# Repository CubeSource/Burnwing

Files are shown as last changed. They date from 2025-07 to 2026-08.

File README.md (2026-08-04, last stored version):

# Burnwing

Burnwing is a burnwire development PCB.

## Features

* Dual-purpose engineering model/flight model to assist in the development of thermal knife release mechanisms and testing of deployables.
    * Optionally, snap off the dev kit portion.
* Powered by USB C with selectable current and voltage limits for easy testing or by picoblade/picolock connectors.
* Default 5V, 1A 

## Renders

### Top

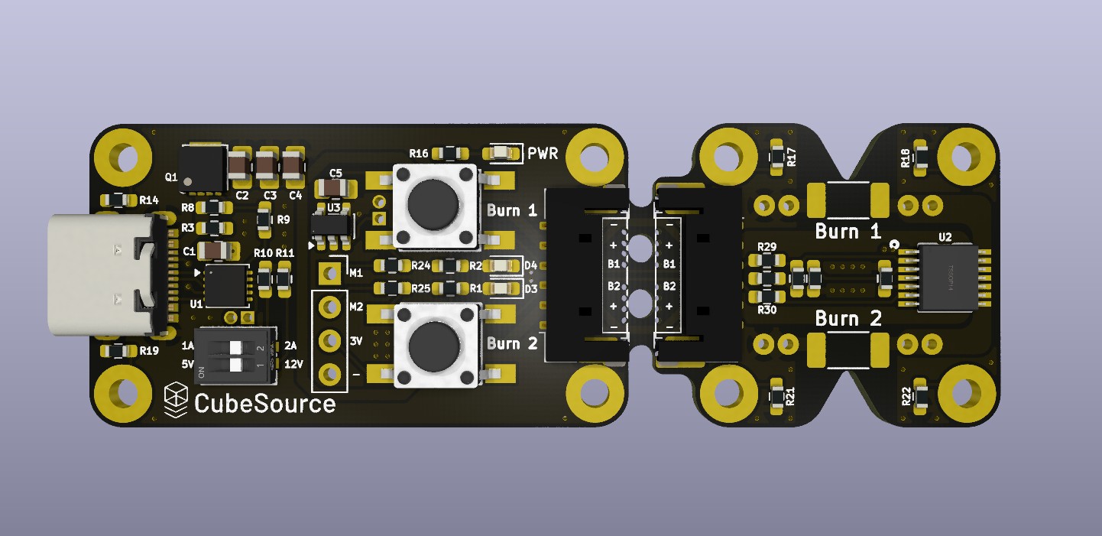
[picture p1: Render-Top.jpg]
Burnwing Rev 3.0 — top


### Bottom

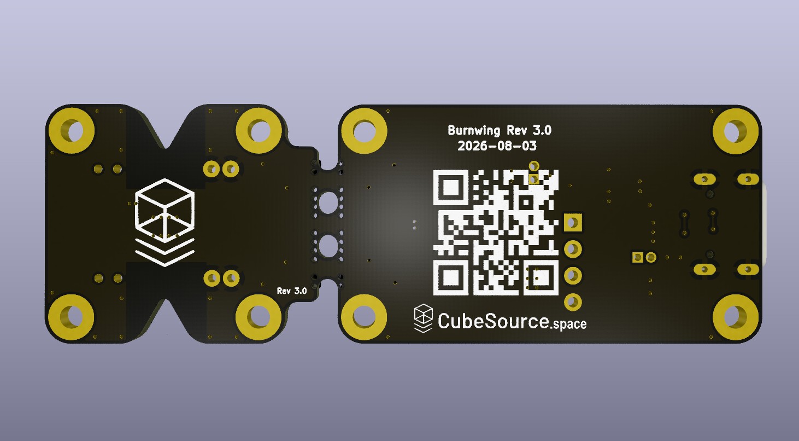
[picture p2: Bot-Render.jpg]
Burnwing Rev 3.0 — bottom


## Additional Resources

* https://www.cubesource.space/resources
* https://docs.google.com/spreadsheets/d/1-gqduE5_rplaJSyHokB8z7FWwOto8bMK/edit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

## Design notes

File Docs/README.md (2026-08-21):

# Burnwing
A dual-purpose engineering/flight model designed to assist in the development of thermal knife release mechanisms and testing of satellite deployables.

## Features
* The dev kit (engineering model) portion includes mouse bites, allowing it to be fully separated from the flight model.
* USB C PD Powered with selectable current and voltage limits for easy testing, or powered through the PicoBlade / Pico-Lock connectors.
* Supply range 5.0-15.0 V, 12 V flight baseline, 18.0 V absolute maximum. The DIP voltage legends (5 V / 12 V) are exact; the current legends read 1 A / 2 A while the values actually requested over USB-PD are 1.25 A / 2.25 A.
* Integrated ESD, Over Temperature, Over Current and Reverse Polarity Protection.

## Renders

### Isometric

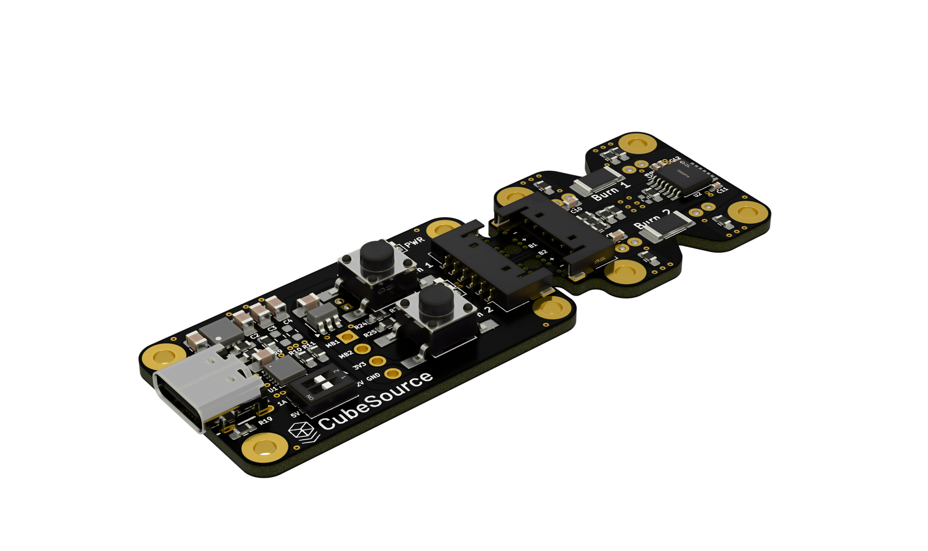
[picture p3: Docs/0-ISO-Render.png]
Burnwing Rev 3.0 — isometric


### Top

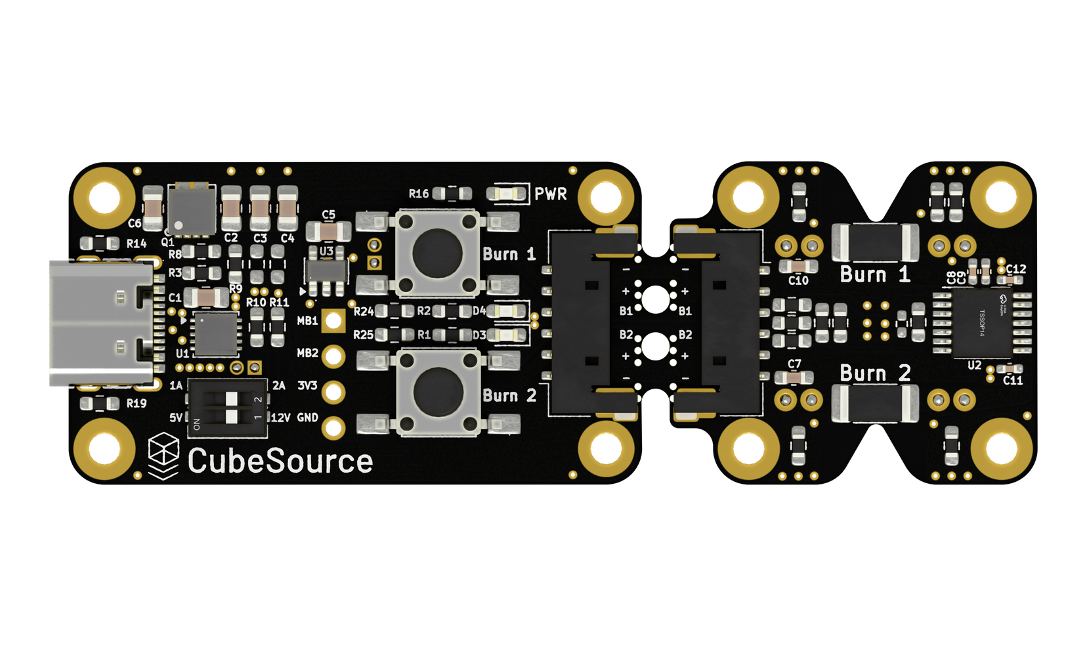
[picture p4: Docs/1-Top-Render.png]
Burnwing Rev 3.0 — top


### Bottom

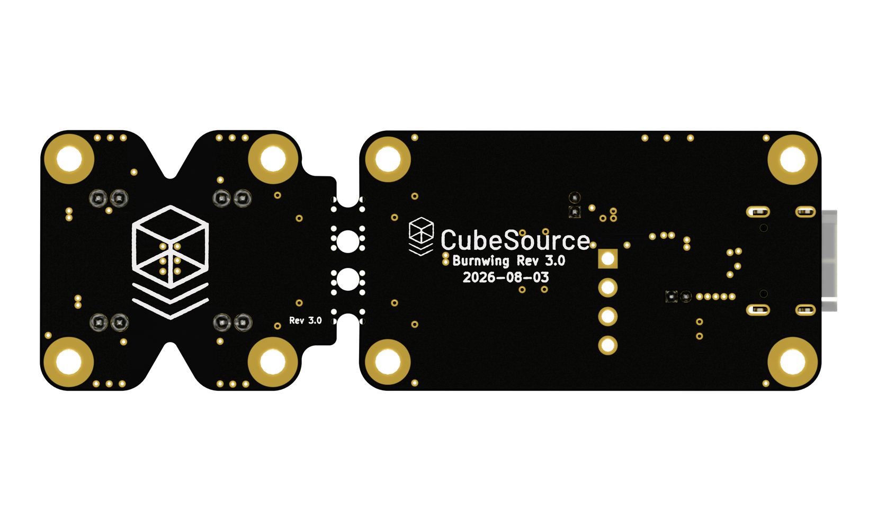
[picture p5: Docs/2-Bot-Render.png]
Burnwing Rev 3.0 — bottom


## Additional Resources

* https://www.cubesource.space/resources
* https://docs.google.com/spreadsheets/d/1-gqduE5_rplaJSyHokB8z7FWwOto8bMK/edit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

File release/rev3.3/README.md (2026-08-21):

# Burnwing Rev 3.0 Production Files

Fabrication and assembly output for the Burnwing Rev 3.0 board, generated from commit `caff272` and carried by the `rev3.3` tag (`df94088`).

Burnwing is a dual-channel thermal knife release mechanism designed for CubeSats and small satellites. It ships as a unified panel carrying two sections joined by mouse bites: a **Flight Model (FM)** and a break-away **Engineering Model (EM)** test fixture.

---

## Features

- **Dual-Purpose Panel**: The break-away Engineering Model (EM) test fixture allows full benchtop testing and can be separated via mouse bites prior to flight integration.
- **USB-C PD Powered**: Selectable voltage and current limits for straightforward lab testing, or powered via Molex PicoBlade / Pico-Lock connectors.
- **Comprehensive Protection**: Integrated ESD protection, over-temperature protection, over-current limiting, and reverse polarity protection.

## Notable Improvements (Rev 2 → Rev 3)

- **Reversible 6-Pin Cable Pinout**: Enables the use of unmodified COTS Molex wire harnesses without polarity orientation errors.
- **High-Side Control Architecture**: Switched from low-side switching (NCV8402ADDR2G) to an Infineon BTS7030-2EPA high-side smart power switch. This keeps the burn elements unenergized until triggered and supports both 3.3V and 5V logic inputs.

---

## Production Files & Release Assets

| File | Description |
|---|---|
| `GERBER-Burnwing-rev3.3.zip` | 9 Gerber layers, PTH/NPTH Excellon drill files with maps, and the `.gbrjob` |
| `BOM-Burnwing-rev3.3.csv` | SMT Bill of Materials (29 line items, 48 placements, every line carrying an LCSC code) |
| `CPL-Burnwing-rev3.3.csv` | Component Placement List (48 placements, including hybrid through-hole parts) |
| `Burnwing-Schematic-rev3.3.pdf` | Complete circuit schematic |
| `Burnwing-rev3.3.step` | 3D CAD assembly model (DNP components excluded) |

---

## Board Specifications

- **Layers**: 2 layers, 1.6 mm thickness
- **Finish**: ENIG (Electroless Nickel Immersion Gold), black solder mask
- **Supply Voltage**: 5.0 V to 15.0 V nominal (12.0 V flight baseline, 18.0 V absolute maximum)
- **Vias**: All 71 vias are untented for thermal and probing accessibility

### DIP switch settings

The voltage legends (5 V / 12 V) are exact. The current legends read 1 A and 2 A; the values actually requested over USB-PD are **1.25 A and 2.25 A**, because the current-select resistor decodes to the nearest tabulated step. This is a ceiling negotiated with the supply rather than a current the board draws, and the board's own requirement is 1.0 A per channel, so neither setting under-supplies it.

---

## Read Before Ordering Assembly

**The CPL includes through-hole footprints deliberately.** `J2`, the USB-C receptacle, is a hybrid part declared `through_hole`. An SMD-only position export drops it and lists 47 parts instead of the correct 48. Do not re-export the position file as SMD-only.

**Two parts must be consigned or hand-fitted, and must come off the uploaded assembly BOM.** Neither is orderable through the assembly house:

| Ref | Part | Reason |
|---|---|---|
| U1 | HUSB238_002DD (C7471904) | Zero supplier stock in the DFN-10 package. Stock held by CubeSource |
| R12, R13 | RR01J36RTB | Burn elements, not an LCSC part. Marked do-not-populate; fitted by CubeSource |

**U2 stock is thin.** The BTS7030-2EPA (C534836) is the flight high-side driver, has no second source in the design, and stood at 433 units. Worth confirming before committing to a run.

---

## Verification & Status

- **ERC**: 0 violations.
- **DRC**: 0 violations beyond the Q1 library note below, 0 unconnected pads, 0 schematic-parity issues.
- **BOM & CPL Parity**: Schematic, board, and the JLCPCB plugin database agree on every part number, so a BOM taken from any of the three orders the same parts. 48-placement CPL.

Eight checks carry reduced severity in the project's rule set and are therefore not represented in those totals: hole-to-copper clearance, solder-mask bridging, courtyard overlap, missing courtyard, silkscreen over copper, silkscreen to board edge, non-plated hole inside courtyard, and footprint filter match.

### Known items

- The Q1 footprint on the board declares the SMD footprint type while the `POWERDI3333` library copy does not, so DRC reports one `lib_footprint_mismatch`. The board is the correct side and Q1 appears in the position file; the warning clears when `(attr smd)` is added to the library footprint. Fixed on `main` in `85b867c` (2026-08-21); the published rev3.3 files predate that commit and still carry the warning.
- `R14` and `R19` are 0 Ω jumpers on the engineering half. The schematic and board specify `C100044`; the JLCPCB plugin database holds `C141796` for the same two parts. Both are 0 Ω 0603, and the flight-half jumpers are unaffected.
- `R33` is a do-not-populate 0 Ω position whose land pattern is 0402 while the assigned part is an 0603 device. Not fitted, so no build is affected.

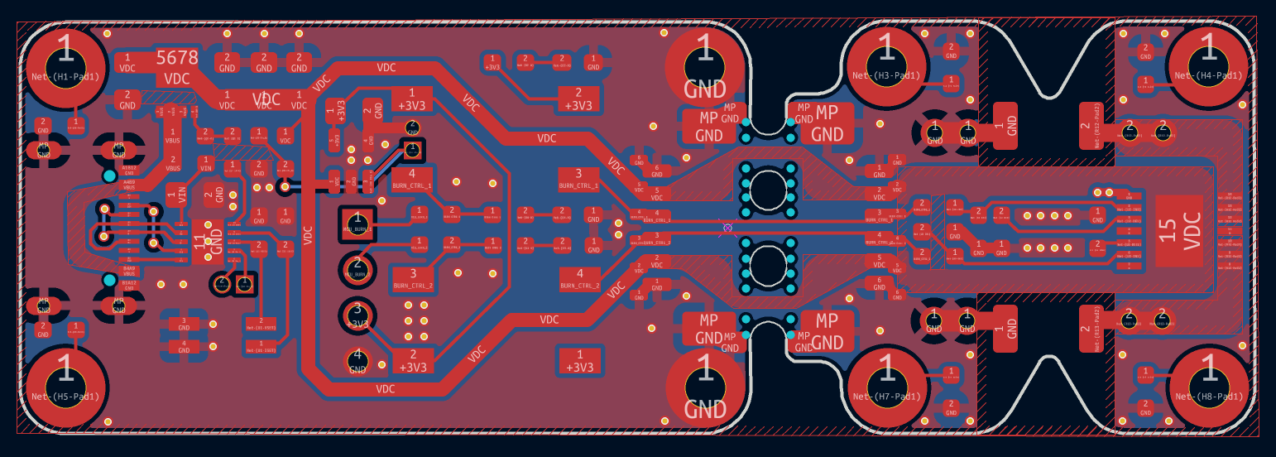
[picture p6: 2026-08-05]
Docs/3-Top-Copper-Layers.png

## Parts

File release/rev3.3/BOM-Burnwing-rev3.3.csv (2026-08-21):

Designator | Comment | Footprint | LCSC | Quantity
Burn1,Burn2 | TSA063G43-250 | Burnwing:KEY-SMD_4P-L6.0-W6.0-P4.50-LS10.0 | C294564 | 2
C1,C4 | 1uF/50V | Burnwing:C_0805_2012Metric_Pad1.18x1.45mm_HandSolder | C28323 | 2
C2,C3,C5,C6 | 4.7uF | Burnwing:C_0805_2012Metric_Pad1.18x1.45mm_HandSolder | C437557 | 4
C7,C10 | 10uF | Capacitor_SMD:C_0603_1608Metric_Pad1.08x0.95mm_HandSolder | C697423 | 2
C8 | 47nF | Capacitor_SMD:C_0402_1005Metric_Pad0.74x0.62mm_HandSolder | C368599 | 1
C9,C11,C12 | 100nF | Capacitor_SMD:C_0402_1005Metric_Pad0.74x0.62mm_HandSolder | C85858 | 3
D3,D4 | LED | Burnwing:LED_0603_1608Metric_Pad1.05x0.95mm_HandSolder | C2286 | 2
D7 | PWR | Burnwing:LED_0603_1608Metric_Pad1.05x0.95mm_HandSolder | C2286 | 1
J2 | USB Type C | Burnwing:USB-C-SMD_G-SWITCH_GT-USB-7010ASV | C2988369 | 1
J5 | Conn_01x06_MountingPin | Burnwing:Molex_Pico-Lock_and_PicoBlade_Mirror | C563981 | 1
J6 | Conn_01x06_MountingPin | Burnwing:Molex_Pico-Lock_and_PicoBlade | C563981 | 1
Q1 | AONR21307 | Burnwing:POWERDI3333 | C3277813 | 1
R1,R2,R16 | 1k5 | Burnwing:R_0603_1608Metric_Pad0.98x0.95mm_HandSolder | C22843 | 3
R3 | 10 | Burnwing:R_0603_1608Metric_Pad0.98x0.95mm_HandSolder | C203240 | 1
R8 | 49k9 | Burnwing:R_0603_1608Metric_Pad0.98x0.95mm_HandSolder | C705780 | 1
R9 | 5k1 | Burnwing:R_0603_1608Metric_Pad0.98x0.95mm_HandSolder | C105580 | 1
R10 | 10K | Burnwing:R_0603_1608Metric_Pad0.98x0.95mm_HandSolder | C116677 | 1
R11 | 14K | Burnwing:R_0603_1608Metric_Pad0.98x0.95mm_HandSolder | C881028 | 1
R14,R19 | 0 | Burnwing:R_0603_1608Metric_Pad0.98x0.95mm_HandSolder | C100044 | 2
R17,R18,R21,R22 | 0 | Burnwing:R_0603_1608Metric_Pad0.98x0.95mm_HandSolder | C141796 | 4
R23,R26 | 10k | Burnwing:R_0603_1608Metric_Pad0.98x0.95mm_HandSolder | C116677 | 2
R24,R25 | 330 | Burnwing:R_0603_1608Metric_Pad0.98x0.95mm_HandSolder | C23138 | 2
R27,R28 | 22k | Burnwing:R_0603_1608Metric_Pad0.98x0.95mm_HandSolder | C144680 | 2
R29,R30 | 3k | Burnwing:R_0603_1608Metric_Pad0.98x0.95mm_HandSolder | C445829 | 2
R32 | 47 | Burnwing:R_0603_1608Metric_Pad0.98x0.95mm_HandSolder | C144656 | 1
SW1 | SW_DIP_x02 | Burnwing:2_Dipswitch | C7430304 | 1
U1 | HUSB238 | Burnwing:WDFN-10-1EP_3x3mm_P0.5mm_EP1.8x2.5mm | C7471904 | 1
U2 | BTS7030-2EPA | Burnwing:PG-TSDSO-14_L4.9-W3.9-P0.65-LS6.0-BL-EP | C534836 | 1
U3 | TPS70933QDBVRQ1 | Burnwing:SOT-23-5 | C90991 | 1

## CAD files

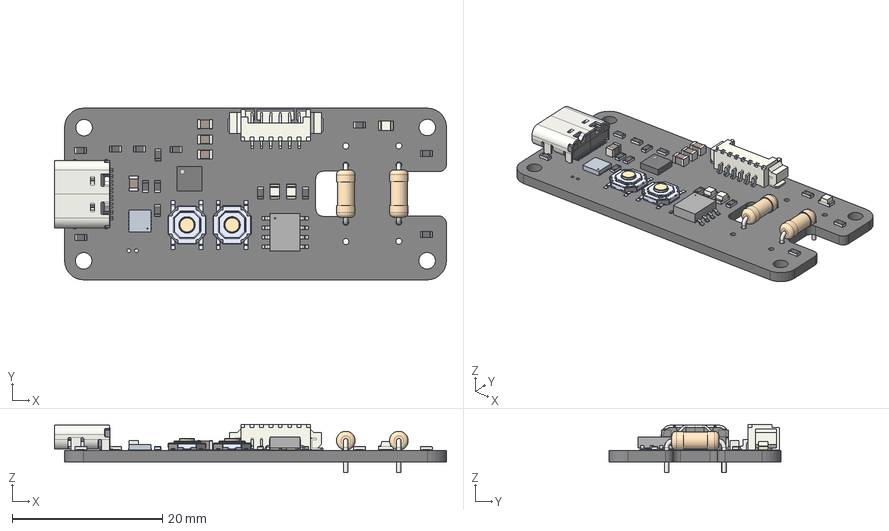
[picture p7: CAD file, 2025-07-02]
Burnwing.step
52.2 x 22.9 x 6.40 mm
C_0805_2012Metric x 4
R_0603_1608Metric x 14
R_Axial_DIN0207_L6.3mm_D2.5mm_P7.62mm_Horizontal x 2
USB_C_Receptacle_GCT_USB4105-xx-A_16P_TopMnt_Horizontal
LED_0805_2012Metric x 3
Molex_PicoBlade_53261-0671_1x06-1MP_P1.25mm_Horizontal
TS-1187A-B-A-B--3DModel-STEP-56544 x 2
SO-8_STM
VSON-8_3.3x3.3mm_P0.65mm_NexFET
CTS-SAT-1-Burnwire-PCB_a4d4ea03 1.29.1
Burnwing_PCB

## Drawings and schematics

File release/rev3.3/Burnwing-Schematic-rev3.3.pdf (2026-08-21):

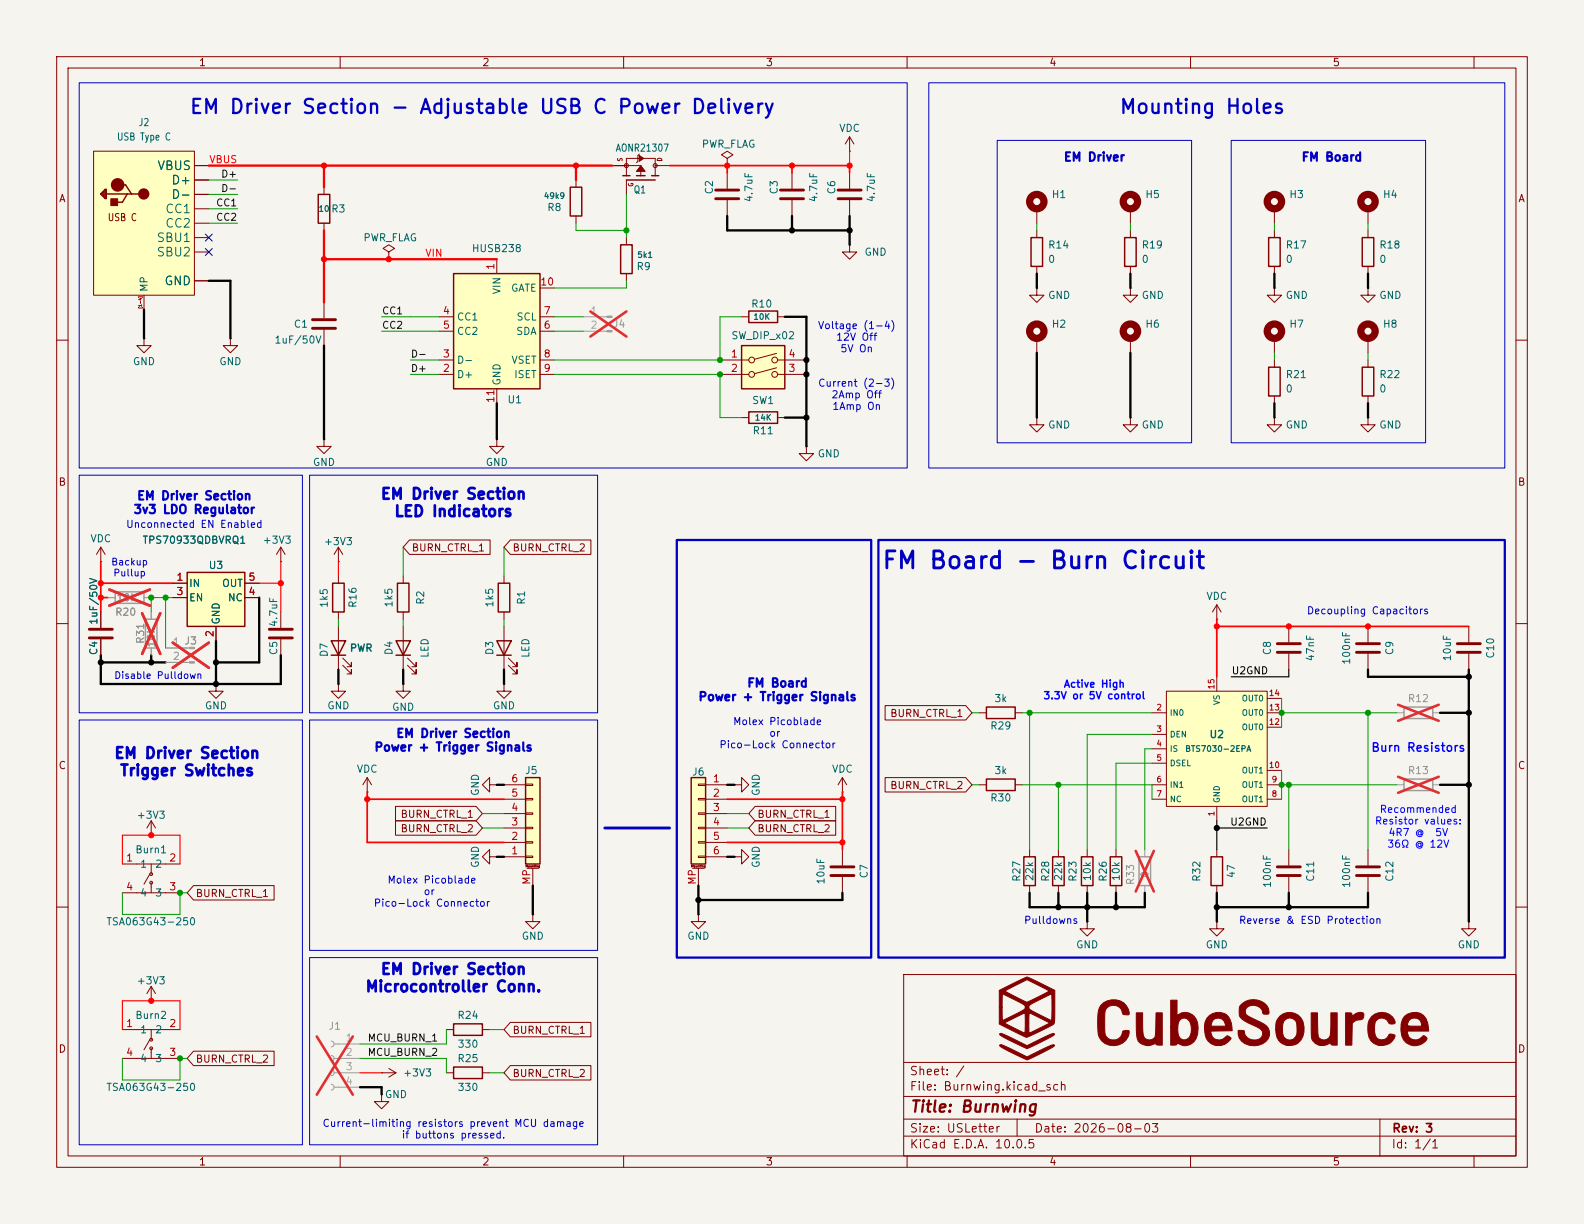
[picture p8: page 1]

Power + Trigger Signals Molex Picoblade or Pico-Lock Connector EM Driver Section - Adjustable USB C Power Delivery

Voltage (1-4) 12V Off 5V On Current (2-3)

2Amp Off 1Amp On Disable Pulldown Unconnected EN Enabled EM Driver Section

FM Board - Burn Circuit

Active High 3.3V or 5V control U3

Current-limiting resistors prevent MCU damage

Size: USLetter | Rev: 3
KiCad E.D.A. 10.0.5 | Id: 1/1

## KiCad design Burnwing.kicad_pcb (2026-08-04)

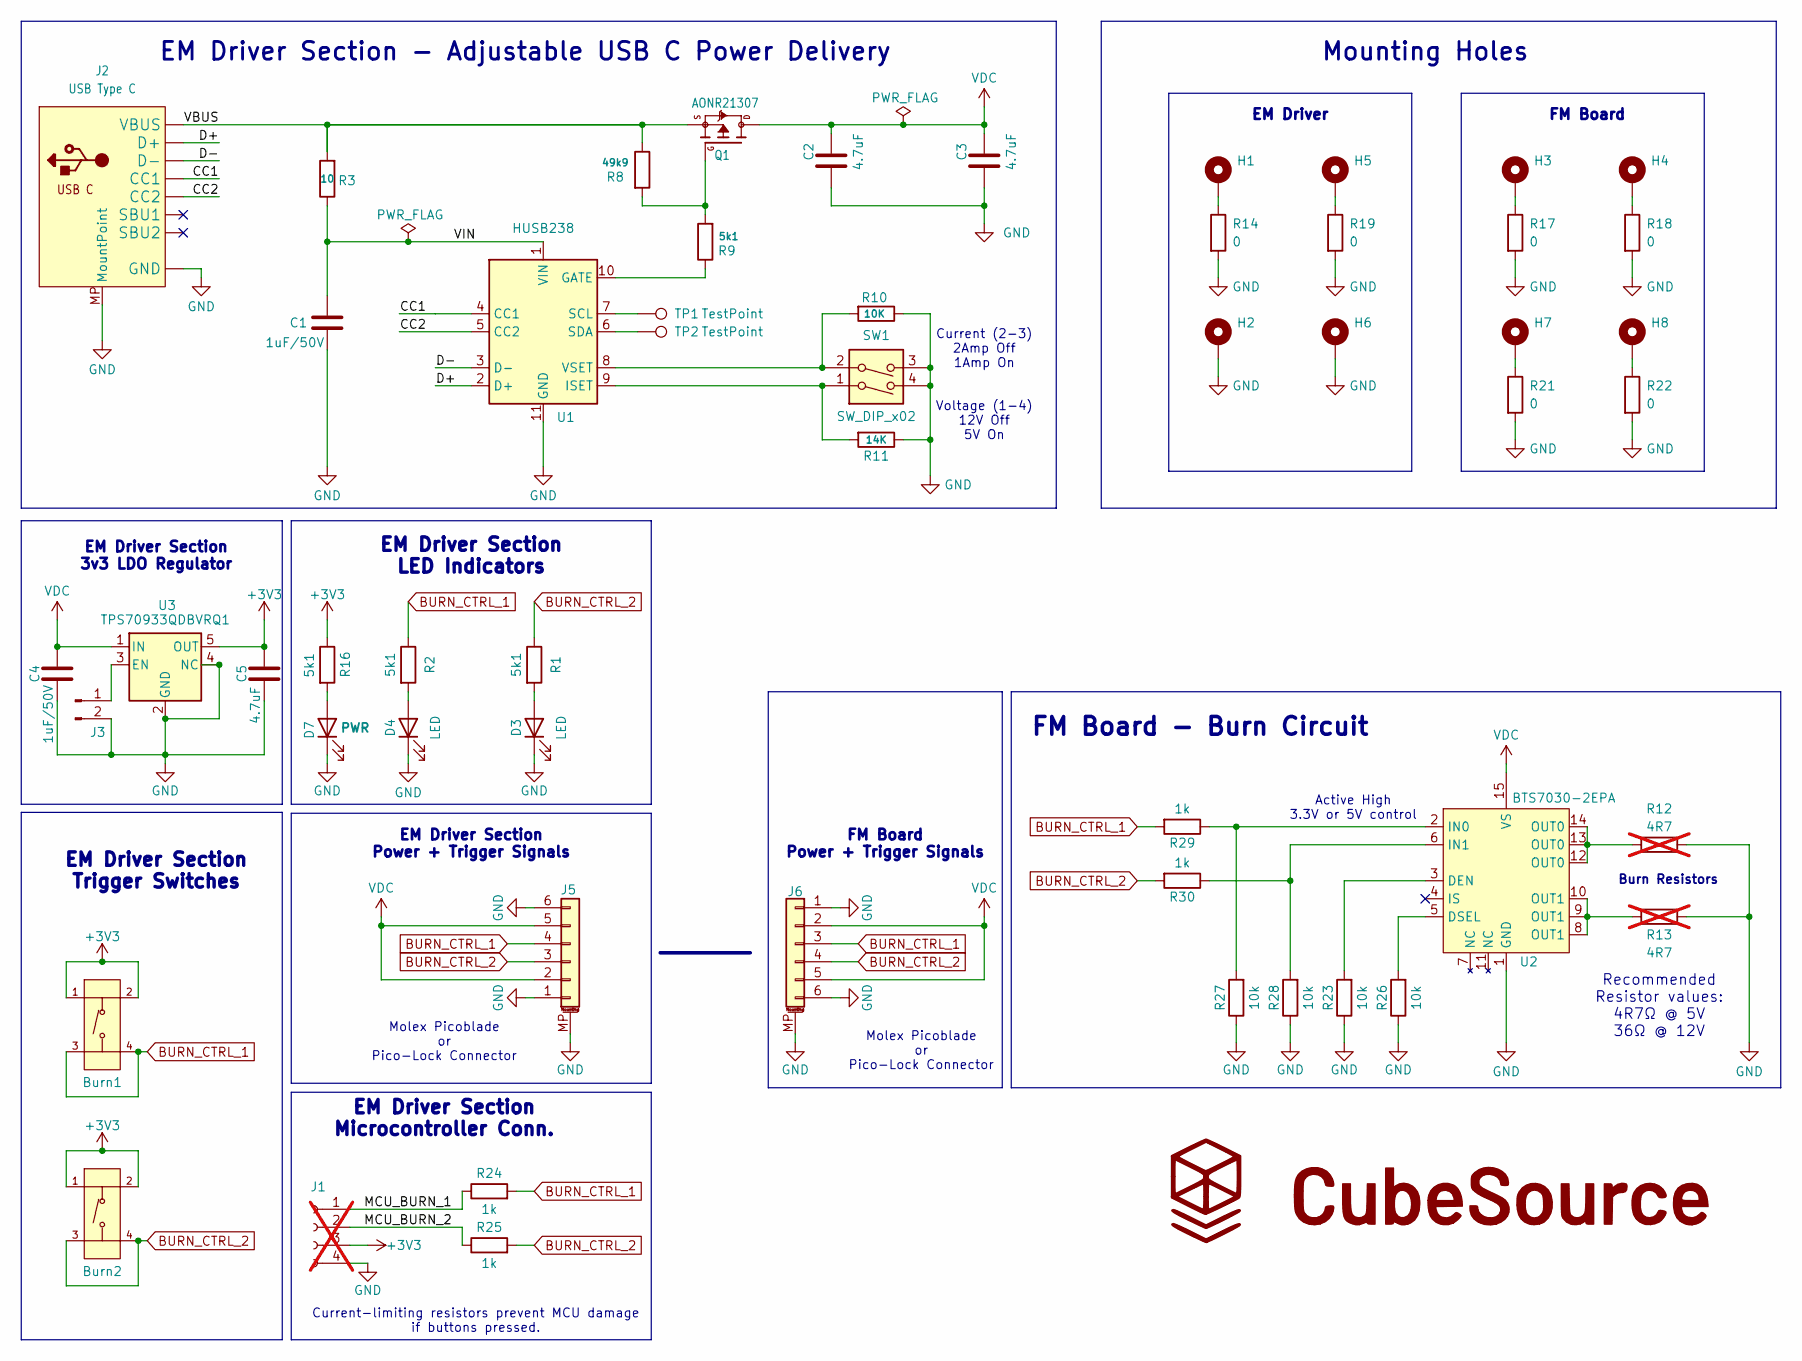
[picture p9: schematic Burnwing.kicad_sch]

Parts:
Burn1, Burn2: KEY-SMD_4P-L6.0-W6.0-P4.50-LS9.5-BR; Voltage Rating (Dc) 12V; Part TS-1187A-B-A-B; LCSC C318884
C1, C4: 1uF/50V; C_0805_2012Metric_Pad1.18x1.45mm_HandSolder; LCSC C28323
C2, C3, C5: 4.7uF; C_0805_2012Metric_Pad1.18x1.45mm_HandSolder; LCSC C437557
D3, D4: LED; LED_0603_1608Metric_Pad1.05x0.95mm_HandSolder; LCSC C94868
D7: PWR; LED_0603_1608Metric_Pad1.05x0.95mm_HandSolder; LCSC C94868
H1, H2, H3, H4, H5, H6, H7, H8: MountingHole_Pad; MountingHole_2.2mm_M2_Pad
J1: Conn_01x04_Socket; PinSocket_1x04_P2.54mm_Vertical; not fitted
J2: USB Type C; USB_C_CUSB31-CFM2AX-01-X; LCSC C2988369
J3: Conn_01x02_Pin; PinSocket_1x02_P1.27mm_Vertical
J5: Conn_01x06_MountingPin-Mirror; Molex_Pico-Lock_and_PicoBlade
J6: Conn_01x06_MountingPin; Molex_Pico-Lock_and_PicoBlade
Q1: AONR21307; POWERDI3333; LCSC C3277813
R1, R2, R9, R16: 5k1; R_0603_1608Metric_Pad0.98x0.95mm_HandSolder; LCSC C105580
R3: 10; R_0603_1608Metric_Pad0.98x0.95mm_HandSolder; LCSC C203240
R8: 49k9; R_0603_1608Metric_Pad0.98x0.95mm_HandSolder; LCSC C705780
R10: 10K; R_0603_1608Metric_Pad0.98x0.95mm_HandSolder; LCSC C95204
R11: 14K; R_0603_1608Metric_Pad0.98x0.95mm_HandSolder; LCSC C105580
R12, R13: 4R7; AxialBurnResistor_No_Cutout; not fitted
R14: 0; R_0603_1608Metric_Pad0.98x0.95mm_HandSolder; LCSC C100044
R17, R18, R19, R21, R22: 0; R_0603_1608Metric_Pad0.98x0.95mm_HandSolder
R23, R26, R27, R28: 10k; R_0603_1608Metric_Pad0.98x0.95mm_HandSolder
R24, R25, R29, R30: 1k; R_0603_1608Metric_Pad0.98x0.95mm_HandSolder
SW1: SW_DIP_x02; 2_Dipswitch
TP1, TP2: TestPoint
U1: HUSB238; WDFN-10-1EP_3x3mm_P0.5mm_EP1.8x2.5mm; LCSC C7471904
U2: BTS7030-2EPA; PG-TSDSO-14_L4.9-W3.9-P0.65-LS6.0-BL-EP; LCSC Part C534836
U3: TPS70933QDBVRQ1; SOT-23-5; LCSC C90991

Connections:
+3V3: Burn1.1 (A), Burn1.2 (B), Burn2.1 (A), Burn2.2 (B), C5.1, J1.3, R16.1, U3.5 (OUT)
/CC1: J2.A5 (CC1), U1.4 (CC1)
/CC2: J2.B5 (CC2), U1.5 (CC2)
/D+: J2.A6 (D+), J2.B6 (D+), U1.2 (D+)
/D-: J2.A7 (D-), J2.B7 (D-), U1.3 (D-)
/MCU_BURN_1: J1.1, R24.1
/MCU_BURN_2: J1.2, R25.1
/VBUS: J2.A4B9 (VBUS), J2.B4A9 (VBUS), Q1.1 (S), Q1.2 (S), Q1.3 (S), R3.2, R8.1
/VIN: C1.1, R3.1, U1.1 (VIN)
BURN_CTRL_1: Burn1.3 (C), Burn1.4 (D), J5.4, J6.3, R2.1, R24.2, R29.2
BURN_CTRL_2: Burn2.3 (C), Burn2.4 (D), J5.3, J6.4, R1.1, R25.2, R30.2
GND: C1.2, C2.2, C3.2, C4.2, C5.2, D3.1 (K), D4.1 (K), D7.1 (K), H2.1 (1_1), H6.1 (1_1), J1.4, J2.A1B12 (GND), J2.B1A12 (GND), J2.MP (MountPoint), J3.2, J5.1, J5.6, J5.MP (MountPin), J6.1, J6.6, J6.MP (MountPin), R10.1, R11.1, R12.1, R13.1, R14.2, R17.2, R18.2, R19.2, R21.2, R22.2, R23.1, R26.1, R27.1, R28.1, SW1.3, SW1.4, U1.11 (GND), U2.1 (GND), U3.2 (GND), U3.4 (NC); also elsewhere on the board
unnamed: D3.2 (A), R1.2
unnamed: D4.2 (A), R2.2
unnamed: D7.2 (A), R16.2
unnamed: H1.1 (1_1), R14.1
unnamed: H3.1 (1_1), R17.1
unnamed: H4.1 (1_1), R18.1
unnamed: H5.1 (1_1), R19.1
unnamed: H7.1 (1_1), R21.1
unnamed: H8.1 (1_1), R22.1
unnamed: J3.1, U3.3 (EN)
unnamed: Q1.4 (G), R8.2, R9.2
unnamed 23: R12.2, U2.12 (OUT0), U2.13 (OUT0), U2.14 (OUT0); also elsewhere on the board
unnamed 24: R13.2, U2.8 (OUT1), U2.9 (OUT1), U2.10 (OUT1); also elsewhere on the board
unnamed: R9.1, U1.10 (GATE)
unnamed: R11.2, SW1.1, U1.9 (ISET)
unnamed 27: TP1.1, U1.7 (SCL); also elsewhere on the board
unnamed 28: TP2.1, U1.6 (SDA); also elsewhere on the board
unnamed: R10.2, SW1.2, U1.8 (VSET)
unnamed: R23.2, U2.3 (DEN)
unnamed: R26.2, U2.5 (DSEL)
unnamed: R27.2, R29.1, U2.2 (IN0)
unnamed: R28.2, R30.1, U2.6 (IN1)
VDC: C2.1, C3.1, C4.1, J5.2, J5.5, J6.2, J6.5, Q1.5678 (D), U2.15 (VS), U3.1 (IN)

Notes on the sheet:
FM Board Power + Trigger Signals
FM Board
Mounting Holes
EM Driver Section 3v3 LDO Regulator
EM Driver Section LED Indicators
EM Driver Section - Adjustable USB C Power Delivery
FM Board - Burn Circuit
Molex Picoblade or Pico-Lock Connector
Recommended Resistor values: 4R7Ω @ 5V 36Ω @ 12V
EM Driver Section Power + Trigger Signals
EM Driver Section Trigger Switches
Voltage (1-4) 12V Off 5V On
Burn Resistors
Current (2-3) 2Amp Off 1Amp On
Current-limiting resistors prevent MCU damage if buttons pressed.
Active High 3.3V or 5V control
EM Driver Section Microcontroller Conn.
EM Driver

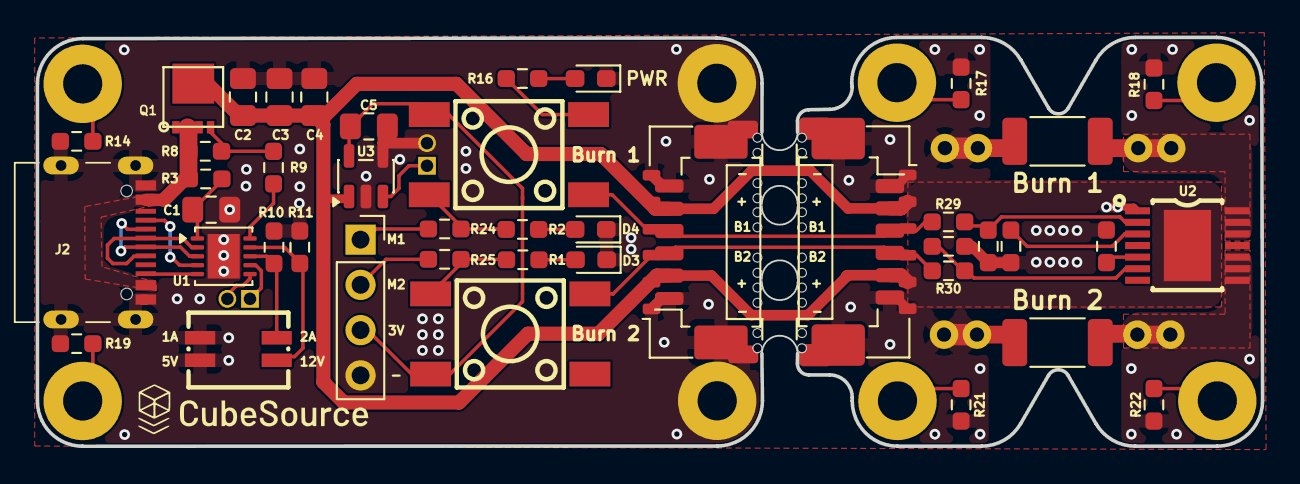
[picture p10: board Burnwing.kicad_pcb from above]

Board: 2 copper layers, 68.7 x 22.9 mm, 57 parts (1 on the bottom side), 35 nets.

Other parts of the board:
.space, .space#2: LOGO; CubeSource
Burn 1, Burn 2: R_2010_5025Metric_Pad1.40x2.65mm_HandSolder
J3#2: Conn_01x02_Pin; PinSocket_1x02_P1.27mm_Vertical

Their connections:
GND: Burn 1.1, Burn 2.1; also elsewhere on the board
unnamed 23: Burn 1.2; also elsewhere on the board
unnamed 24: Burn 2.2; also elsewhere on the board
unnamed 27: J3#2.1; also elsewhere on the board
unnamed 28: J3#2.2; also elsewhere on the board

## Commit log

2025-05-18 Initial upload
    Reupload of Rev1 to begin Rev2 updates
    [Burnwing.kicad_pcb, Burnwing.kicad_sch]
2025-06-22 Changed to USB C power
    Switched our regulator for selectable usb C power delivery
    [Burnwing.kicad_pcb, Burnwing.kicad_sch]
2025-06-22 Updated Schematic
    [Burnwing.kicad_sch]
2025-06-23 updated layou/schematic
    [Burnwing.kicad_pcb, Burnwing.kicad_sch]
2025-06-23 Routing updates
    [Burnwing.kicad_pcb, Burnwing.kicad_sch]
2025-06-26 Minor updates
    [Burnwing.kicad_pcb, Burnwing.kicad_pcb_bom.csv, Burnwing.kicad_pcb_positions.csv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]
2025-07-02 Cleaned up Schematic and exported project libraries
    [Burnwing.kicad_pcb, Burnwing.kicad_pcb_bom.csv, Burnwing.kicad_pcb_positions.csv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]
2025-07-02 fixed embedded models
    [Burnwing.kicad_pcb, Burnwing.kicad_sch]
2025-07-18 Reworked the layout
    [Burnwing-CuBottom.gbr, Burnwing-CuTop.gbr, Burnwing-EdgeCuts.gbr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]
2025-07-18 Layout completed
    [Burnwing.kicad_pcb]
2025-07-18 Cleaned schematic a bit
    [Burnwing.kicad_pcb, Burnwing.kicad_sch]
2025-07-19 Reworked usb power and cleaned up layout
    [Burnwing.kicad_pcb, Burnwing.kicad_sch]
2025-07-22 Make some traces widers and added decals
    Increased Trace width near R1 and R2 thru holes.
    Also added decals
    [Burnwing.kicad_pcb, Burnwing.kicad_sch]
2025-07-22 Cleaned up files and added part numbers
    Updated Schematics
    Updated STEP files
    Regenerated Project Libraries
    Added Part Numbers
    [Burnwing-CuBottom.gbr, Burnwing-CuTop.gbr, Burnwing-EdgeCuts.gbr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]
2025-07-22 Added Decals and Labels
    [Burnwing.kicad_pcb]
2025-11-17 4 layer v3 template
    [Burnwing.kicad_pcb, Burnwing.kicad_sch]
2025-11-26 added dip switch
    add dip switch and adjusted layout a bit
    [Burnwing.kicad_pcb, Burnwing.kicad_sch]
2025-11-26 Library Fix
    [Burnwing.kicad_pcb]
2025-11-26 google drive upload
    [Burnwing.kicad_pcb]
2025-12-22 Separated Version
    -Added dipswitch for Vset and Iset
    -Added tentative microcontroller and jumper pins
    -Separated flight and not flight modes
    -Removed SCL/SDA
    [Burnwing.kicad_pcb, Burnwing.kicad_sch]
2025-12-22 Schematic Update
    [Burnwing.kicad_sch]
2026-01-04 Fixed Vias Issues
    [Burnwing.kicad_pcb]
2026-01-04 QR Code Shifting
    Moved Jumper 2, QR Code, CubeSource link, and Burnwing Rev2
    [Burnwing.kicad_pcb]
2026-01-05 fixing traces/vias
    [Burnwing.kicad_pcb]
2026-01-05 Fixed VDC traces
    [Burnwing.kicad_pcb, Burnwing.kicad_sch]
2026-01-05 Changed jumper headers
    Changed jumper pins to 1.27 size
    [Burnwing.kicad_pcb]
2026-01-05 VBUS Trace width fix
    [Burnwing.kicad_pcb]
2026-01-06 Removed micro burn resistors
    Removed micro burn resistors and cleaned up layout. Swapped micro pin holes to 2.54 and cleaned up layout.
    [Burnwing.kicad_pcb, Burnwing.kicad_sch]
2026-01-06 updated dates
    [Burnwing.kicad_sch]
2026-06-12 breakaway burnwing mini
    Form factor changes
    [Burnwing-CuBottom.gbr, Burnwing-CuTop.gbr, Burnwing-EdgeCuts.gbr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]
2026-06-12 file cleanup
    [Burnwing.kicad_pcb]
2026-06-13 library cleanup
    [Burnwing.kicad_pcb, Burnwing.kicad_sch]
2026-06-14 2layer rework
    [Burnwing-CuBottom.gbr, Burnwing-CuIn1.gbr, Burnwing-CuIn2.gbr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]
2026-06-24 pre ai save
    [Burnwing.kicad_pcb, Burnwing.kicad_sch]
2026-07-09 fix: Merge libraries, fix all ERC issues
    [Burnwing-CuBottom.gbr, Burnwing-CuIn1.gbr, Burnwing-CuIn2.gbr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]
2026-07-09 docs: Update README with modern render-
    [Burnwing.kicad_pcb]
2026-07-13 feat: Separate EM/FM sections in schematic, add extra connector, add LDO
    [Burnwing.kicad_pcb, Burnwing.kicad_sch]
2026-07-13 fix: Change MCU connector to 1x03
    [Burnwing.kicad_sch]
2026-07-14 fix: Replaced TLV73333 with automotive TPS70933 LDO
    - TLV73333 (5.5V max) was too low for 12VDC
    - Swapped U3 to TPS70933QDBVRQ1 (C90991): AEC-Q100, 30V in, 150mA, pin-compatible
    - Bumped C6 to 4.7uF (C437557) — TPS709 needs >=2.2uF output cap
    [Burnwing.kicad_sch]
2026-07-14 chore: Imported L78M05 library assets, fixed library tables
    - Imported L78M05ABDT-TR symbol, SOT-89/TO-252 footprints and 3D models via easyeda2kicad
    - Registered Library.kicad_sym in sym-lib-table
    - Fixed broken Library.pretty path in fp-lib-table
    - KiCad project file housekeeping (used_designators)
2026-07-14 chore: Removed unused library assets, untracked .kicad_prl
    - Removed L78M05 symbol, SOT-89/TO-252 footprints and 3D models — not referenced by the design
    - Dropped their dangling entries from sym-lib-table and fp-lib-table
    - Untracked Burnwing.kicad_prl (already in .gitignore, was committed before the rule)
    - Added .history/ to .gitignore
2026-07-14 fix: Aligned schematic to 50mil grid, removed dangling wires
    [Burnwing.kicad_sch]
2026-07-14 Started new layout
    [Burnwing.kicad_pcb]
2026-07-14 Most major components places/drawn
    [Burnwing.kicad_pcb]
2026-07-19 layout routing
    [Burnwing.kicad_pcb, Burnwing.kicad_sch]
2026-07-22 layout stuff
    [Burnwing.kicad_pcb, Burnwing.kicad_sch]
2026-08-04 Cleaned up layout and libraries
    [Burnwing-CuBottom.gbr, Burnwing-CuIn1.gbr, Burnwing-CuIn2.gbr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]
2026-08-04 Self-contained libraries, Rev 3.0 renders, README
    Move footprint/symbol assignments into the project-local Burnwing.pretty
    and Burnwing.kicad_sym libraries so the project builds without external
    library dependencies. Adds PinSocket 1x02/1x04 and the DB128L-5.08-2P
    screw terminal (symbol, footprint and 3D model).
    Add top and bottom renders of Rev 3.0 and reference them from the README,
    replacing the stale docs/Render_Top.png link.
    Ignore .history_trim/ and internal PCB review reports.
    Claude-Session: https://claude.ai/code/session_01PXHPcjwL7EimSN7b4jQgcZ
    [Burnwing.kicad_pcb, Burnwing.kicad_sch]
2026-08-04 Remove unused library assets
    Drop the DB128L-5.08-2P screw terminal (footprint and 3D models) along
    with three other footprints no library or design references:
    CONN-TH_2P-P5.08_DB128L-5.08-2P-BK-S
    CubeSource_LOGO (superseded by CubeSource + LOGO)
    PinHeader_1x03_P2.54mm_Vertical
    WQFN-20_L3.0-W3.0-P0.40-TL-EP1.7
    Also removes Burnwing.pretty.kicad_sym, an orphan single-symbol library
    that was never registered in sym-lib-table.
    Verified no change in ERC (18 warnings), DRC (0 violations, 4 unconnected)
    or schematic parity (45) before and after.
    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
2026-08-04 Layout complete - Ready for review
    [Burnwing.kicad_sch]
2026-08-05 Cleaning up files
    [Burnwing.kicad_sch]
2026-08-05 Rev 3.0 renders: corrected component materials, transparent background
    Fix black plastic reading as grey metal on connectors, switches, ICs and chip
    resistors, and give the USB-C a steel shell. Render on a transparent background.
2026-08-06 Even out render lighting across the board
    Directional key lit the connector end ~2x brighter than the break-off end. Sun
    key plus mirrored side lights and more ambient flattens it to 1.15x at the same
    brightness as the bright end was.
2026-08-06 Restore silver metal on USB-C shell and tact switch caps
    Base colour on a metallic surface is its reflectance, so the previous
    near-black greys read as grey plastic rather than dark steel. Set them to
    nickel/stainless reflectance and drop roughness so the faces fall off
    against each other instead of flattening to one tone.
    Claude-Session: https://claude.ai/code/session_01AE3Esar3cApVa5e8kdtP8i
2026-08-06 Re-render at 2x supersampling and lift brightness
    Rendered at 3312x1968 and downsampled to delivery size, so the fine
    silkscreen and pad outlines resolve instead of aliasing. Averaging also
    removes noise the denoiser was smoothing over, which makes the files
    smaller than the ones they replace despite the extra detail.
    Brightness is a gain on the tone-mapped output rather than scene
    exposure: exposure is linear and the view transform is not a power law,
    so it lifts shadows twice as hard as mids and the black components stop
    reading as black.
    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
2026-08-16 Add Pico-Lock connector part, teardrops, and panel break tabs
    Schematic:
    - Add local 5040500691 symbol (Molex Pico-Lock 504050-0691) with datasheet
    - Add R32 (47R 0603); retarget R27 to the local Burnwing:R symbol
    - Switch the 6-pin connector from the mirrored footprint variant to the
    standard Molex_Pico-Lock_and_PicoBlade
    PCB:
    - Apply teardrops to pads and vias (13 -> 155 zones)
    - Rework routing: 180 -> 252 track segments, 73 -> 66 vias
    - Rework the panel edge: add four BreakLine_1h_D0.5mm_P0.85mm tabs,
    drop one mouse bite
    Libraries:
    - Add CONN-SMD_6P-P1.50_A1501WRB-S-6P footprint with STEP/WRL models
    - Rename Molex_Pico-Lock_and_PicoBlade2 to Molex_Pico-Lock_and_PicoBlade_Mirror
    - Ad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
    [Burnwing.kicad_sch]
2026-08-16 Apply design review fixes, clean up BOM and footprint library
    Board now passes DRC with 0 violations, 0 unconnected items and 0 schematic
    parity errors. ERC is down to one pre-existing power_pin_not_driven on U2 pin 1.
    Component values (from the design review):
    - R29, R30: 1k -> 3k on the control-line series resistance. At 12 V into a
    3.3 V host this is 25 mW against a 50 mW derated budget; 1k gave 76 mW and
    failed the 50% derate. 3k + the 1k on the J1 path stays under the 4.7k the
    driver datasheet recommends
    - R1, R2, R16: 5k1 -> 150R on the LED series resistors. 5k1 gave ~0.25 mA and
    was effectively invisible. 150R gives 8.7 mA at 3.3 V and stays safe at 20 mA
    if a control line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
    [Burnwing.kicad_sch]
2026-08-17 Correct SW1 pole assignment so legends match function
    The DIP switch poles drove the opposite functions to their printed legends:
    the pole marked for voltage switched ISET, and the pole marked for current
    switched VSET.
    Swap the pole assignments so each matches its legend:
    - SW1 pin 1 (switch 1, pins 1-4) now drives VSET
    - SW1 pin 2 (switch 2, pins 2-3) now drives ISET
    Schematic annotation updated to match: "Voltage (1-4)" and "Current (2-3)",
    previously "(2-3)" and "(1-4)" respectively.
    Resistor values are unchanged and were always correct - R10 = 10k on VSET
    requests 12 V open / 5 V closed, R11 = 14k on ISET requests 2.25 A open /
    1.25 A closed. Only the mapping of function to physical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
    [Burnwing.kicad_sch]
2026-08-17 Docs updates
    [Burnwing.kicad_sch]
2026-08-17 Fix control-input drive margin, correct LED part, complete BOM
    An external controller could not be guaranteed to assert U2 IN0/IN1. The 150R
    LED series resistors clamped BURN_CTRL to ~2.05 V, putting the inputs at 1.97 V
    against a 2.19 V requirement - V_DI(TH) max 2.0 V plus the GND-network offset
    (I_GND 4 mA x R32 47R = 188 mV). Worst case was -220 mV, so the manual buttons
    fired a channel while an external controller might not, and only at the hot
    corner or on a worst-case part.
    Input network:
    - R1, R2, R16: 150R -> 1k5. The LED is a clamp, not a load, so the node sits at
    a conductance-weighted average of the rail and Vf. This cuts the LED's
    authority over the control node from 87% to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
    [Burnwing.kicad_sch]
2026-08-17 Ignore review workspace and kicad-cli report artifacts
    The repo is public, so local review scratch must never be committable by
    accident.
    - .review/ two-model review workspace (queue, findings, ledger, backups)
    - .gemini/ Antigravity IDE workspace config
    - *-erc.rpt / *-drc.rpt kicad-cli report output
    Housekeeping only. No design content.
2026-08-17 Move tier-neutral flight-half passives to AEC-Q200 parts
    Eight flight-half resistors carried commercial-grade parts. All three
    groups have an AEC-Q200 equivalent at the same 0603 land pattern, same
    value and tolerance, and the same JLC library tier, so the qualification
    upgrade costs nothing in assembly setup.
    R23, R26 (10k) C98220 -> C116677 Yageo AC0603FR-0710KL
    R29, R30 (3k) C881244 -> C125893 Yageo AC0603FR-073KL
    R17,R18,R21,R22 (0R) C100044 -> C141796 Yageo AC0603JR-070RL
    All three are JLC Extended before and after, so no feeder setup charge is
    added. Every part number was confirmed by live catalogue lookup - value,
    package, tolerance, manufacturer a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
    [Burnwing.kicad_sch]
2026-08-17 Complete AEC-Q200 coverage on the flight half, accepting Extended tier
    The remaining three flight-half passives kept commercial parts because the
    AEC-Q200 equivalents sit in JLC's Extended library and add a feeder setup
    charge. On a ~20 board run that charge is negligible against the cost of
    the payload, so qualification wins over assembly convenience.
    R27, R28 (22k) C31850 -> C144680 Yageo AC0603FR-0722KL
    R32 (47R) C23182 -> C144656 Yageo AC0603FR-0747RL
    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
    [Burnwing.kicad_sch]
2026-08-18 Propagate schematic part numbers to the board and refill zones
    Update PCB from Schematic pushed LCSC fields to 13 footprints that had gone
    stale against the schematic: the 11 flight-half passives moved to AEC-Q200 in
    4c3da15 and 7a81302, plus J5/J6 which carried no board LCSC at all. Fab tools
    that build their BOM from board footprint fields were still reading the old
    commercial part numbers.
    The field update triggered a zone and teardrop refill that left one clearance
    error at R23 pad 2; a full refill clears it. Schematic to board LCSC parity is
    0 mismatches across all 57 matched components, DRC is 0 violations and
    0 unconnected over three runs, ERC is 0.
2026-08-18 Swap the USB-C receptacle for the GT-USB-7010ASV
    Replace X1 (USB_C_CUSB31-CFM2AX-01-X) with J2, a GT-USB-7010ASV
    (LCSC C2988369), and add the matching symbol, footprint, and STEP/VRML
    models. The BOM and CPL now carry a sourceable part for the USB input,
    which the previous placeholder connector did not.
    Move the LCSC and MPN fields onto the symbol instances so the JLC BOM
    export picks them up from the board rather than from stale cached
    library data.
    Re-save the footprint library and sym-lib-table in the current KiCad
    file format, and refill the zones after the connector swap. Project
    settings tighten the zone minimum thickness to 0.2 mm, trim the default
    silk pad height to 1.24 mm, and gr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
    [Burnwing.kicad_sch]
2026-08-20 Break up the paste apertures on the U2 and Q1 thermal pads
    Both large bottom-terminated pads had a single full-area paste
    aperture: U2 (BTS7030-2EPA) over 10.60 mm2 and Q1 (AONR21307) over
    5.29 mm2. Printing 100% of that area deposits far more solder than the
    joint needs, which floats and tilts the part during reflow and traps
    voids under the slug.
    Replace each with a windowpane pattern, matching how the U1 WDFN
    footprint already handles its exposed pad:
    U2 6 apertures of 1.05 x 1.10 mm -> 62.0% coverage, 0.375 mm webs
    Q1 4 apertures of 0.90 x 0.95 mm -> 61.4% coverage, 0.300 mm webs
    (U1 sits at 63.0% for comparison.) The pads keep their copper and mask
    layers; only F.Paste moves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
2026-08-20 Reconnect the burn control inputs and rework the U2 routing
    BURN_CTRL_1 and BURN_CTRL_2 were open circuit at R29 pad 2 and R30
    pad 2. With both BTS7030 inputs stranded behind their series 3k
    resistors, the 22k pulldowns held IN0 and IN1 low and neither burn
    channel could ever be commanded. Rerouting the area around U2 closes
    both paths: DRC reports zero unconnected pads, down from two.
    Also in this snapshot:
    - R21 loses its "not in schematic" attribute, so schematic sync
    reaches it again
    - the C7/C9 reference-designator silkscreen overlap is resolved
    - the CubeSource logo footprint matches its library copy again
    - 25 new track segments and 2 new vias, mostly /U2GND and the U2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
    [Burnwing.kicad_sch]
2026-08-20 Strap U2 pin 7 to IN1 with a wire instead of a stray label
    The board routes the IN1 signal out through U2 pad 7. The Infineon
    data sheet (Rev. 1.11, Table 2) lists pins 7 and 11 as "n.c. - Not
    connected, internally not bonded", so the pad is an isolated lead-frame
    stub and borrowing it as a routing bridge is electrically sound.
    The schematic tried to record that with a bare Net-(U2-IN1) label
    dropped on pin 7. A label with no wire under it does not connect
    anything, so ERC reported it as a dangling label. Replace it with an
    actual wire from pin 6 to pin 7, which is what the copper does.
    ERC errors go from one to zero. One warning remains and is accurate:
    pin 7 is still typed as a no-connec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
    [Burnwing.kicad_sch]
2026-08-20 Retype U2 pin 7, set the Q1 footprint type, and settle the LCSC fields
    Clears the last ERC warning and every schematic-parity issue.
    U2 pin 7 changes from a no-connect to a passive pin in the symbol, and
    the schematic's cached copy is updated to match. The board routes IN1
    out through pad 7, which the Infineon data sheet lists as internally
    unbonded, but a no-connect pin is excluded from its net by the
    netlister no matter what is wired to it. With the pin retyped, pad 7
    resolves to Net-(U2-IN1) on both sides, so the DRC exclusion that was
    masking the conflict is deleted rather than carried.
    Q1 gains a footprint type of SMD on the board. Without it the part
    resolved as unspecified and fell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
    [Burnwing.kicad_sch]
2026-08-20 Refresh the board renders for the current revision
    The published renders still showed the pre-GT-USB-7010ASV receptacle
    and the flight half before the burn-control routing was reconnected.
    Regenerated from the current board at the same 1656x984 with the same
    transparent background and framing.
    Produced with kicad-cli's raytracer rather than the Blender pipeline
    that made the previous set, so the soldermask reads dark brown where
    it sits over bare laminate instead of the flat black of the hand-tuned
    Blender materials. The geometry, parts and silkscreen are current.
    Docs/3-Top-Copper-Layers.png is a PCB editor screenshot rather than a
    render and is not referenced by the README, so it is left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
2026-08-21 Carry the current part numbers in the schematic
    C7, C9, C10, C11, R29 and R30 were selected on the board and in the
    JLCPCB plugin database but never written back to the schematic, so the
    schematic still held blanks for C7, C9 and C11, the superseded C194427
    for C10, and the 100 mW C125893 for R29 and R30.
    That gap already cost the board once: an Update PCB from Schematic
    pushed the stale values back down and silently reverted all four of the
    assigned parts, taking the flight bulk capacitors off the AEC-Q200 part
    and the control-line series resistors off the 250 mW part. Parity
    reported clean throughout, because both sides agreed - on the wrong
    values.
    The schematic now carries what the plu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
    [Burnwing.kicad_sch]
2026-08-21 Sync the board to the schematic part numbers
    Update PCB from Schematic pulls the six LCSC fields committed in 810409a
    onto the placed footprints: C7 and C10 to C697423, C9 and C11 to C85858,
    R29 and R30 to C445829. Board and schematic now agree, and they agree
    with the JLCPCB plugin database, so a BOM taken from any of the three
    orders the same parts.
    Also in this snapshot, from the same editing session: a zone and
    teardrop refill.
    ERC 0 violations. DRC 0 unconnected pads and 0 schematic parity issues.
    The SMD-only position file lists 47 parts.
    One DRC warning remains, and is expected: the Q1 footprint on the board
    carries the SMD footprint type while the POWERDI3333 library copy does
    not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
2026-08-21 Add the rev3.3 production files
    Fabrication and assembly output generated from caff272: gerbers and
    Excellon drill files, BOM, position file, schematic PDF and STEP.
    The position file is exported with through-hole footprints included.
    J2 is a hybrid USB-C receptacle declared through_hole, so an SMD-only
    export drops it and lists 47 placements against the correct 48.
    The BOM carries an LCSC code on all 29 lines. Two parts still have to be
    consigned or hand-fitted and should come off the uploaded assembly BOM:
    U1, which has zero supplier stock in the DFN-10 package, and the R12/R13
    burn elements, which are not LCSC parts. The accompanying README records
    both, along with the thin U2 stock and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
    [BOM-Burnwing-rev3.3.csv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]
2026-08-21 Update README title formatting
    Removed the word '—' from the title in README.
2026-08-21 Rebuild the board renders with the Blender pipeline
    The Aug 20 set was produced with kicad-cli's raytracer after the Blender
    material overrides stopped matching the board. That table is keyed to the
    embedded model hashes, and three of those moved when parts changed: the
    J5/J6 connector, the Burn 1/Burn 2 tact switches, and U2. Re-keyed by mesh
    size, so all twelve overrides land again and the soldermask reads black
    rather than the raytracer's brown over bare laminate.
    J2 renders with the previous GCT USB4105 receptacle, which is still
    embedded in the board and reads closer to the real part than the
    GT-USB-7010ASV model does. This is a render-only substitution made against
    a scratch copy of t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
2026-08-21 Correct the via count and the current-limit figures in the READMEs
    Three fixes that were wrong rather than merely out of date:
    - The rev3.3 board carries 71 vias, not 66. Counted from the tagged
    board: 71 via records, none blind or buried.
    - The DIP current legends read 1 A and 2 A, but the values actually
    requested over USB-PD are 1.25 A and 2.25 A, because the current-select
    resistor decodes to the nearest tabulated step. The voltage legends
    (5 V / 12 V) are exact. Both READMEs said "Default 5V, 1A".
    - Docs/README.md did not state the supply range at all; it now carries
    5.0-15.0 V with the 12 V baseline and 18.0 V absolute maximum.
    The production README had also lost its consig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
2026-08-25 Bottom side through hole pad mask changes
2026-09-01 Publish the as-built Rev 3.0 production files
    The files carried under release/rev3.3 were exported on 2026-08-20 and do
    not match the boards that were built. Replace them with the set that was
    actually uploaded for the 2026-08-24 build:
    - BOM: rev3.3 listed R14 and R19 as C100044. All six 0 ohm jumpers were
    fitted with C141796.
    - CPL: rev3.3 held raw board positions with no orientation corrections.
    U3 was 90 degrees out, and J2, J5, J6 and Q1 were offset.
    - Gerbers: rev3.3 predated the POWERDI3333 footprint fix and the
    bottom-side through-hole pad mask change.
    Verified against the order: the BOM matches all 25 parts and 48
    placements, and the Gerbers reproduce from this board on ever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
